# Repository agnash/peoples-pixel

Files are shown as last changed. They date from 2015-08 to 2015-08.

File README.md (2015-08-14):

Copyright (c) 2015, Aaron Nash, Dominic Schira, and James Cuadros. This file is licensed under the terms of the "GPL (v2)" license. Please see the file LICENSE.md included in this distribution for licensing terms.

Contact, issues and contributing information is at the bottom of this readme.

# The People's Pixel

This project combines a Raspberry Pi and Arduino Uno, along with necessary peripherals, to form a compact
system capable of performing user-initiated image capture and presentation, such as would be typical in a "photo-booth" machine. The system currently supports the use of a segment display as a countown timer and a button as the trigger.

This take on a DIY, portable photobooth solution is unique in that it allows builders to make use of the amateur or professional camera they may already have (compatable camera list is linked to below). Since the system separately handles all hardare accessory control via a microntroller, folks with some programming and electronics experience can extend the machine to make use of even more 'gizmos' that may enhance the user experience (i.e. a flash bulb, or print-to-tape device).

The system has been built into an initial working prototype. Our version represents only one possible enclosure design and equipment configuration. For some pictures of construction check out our [short photo blog](https://github.com/agnash/peoples-pixel/wiki/Blog). <add picture of startup splash screen to blog>

# Disclaimer
This project may involve some basic work with electronics. While the methods provided here have been tested under certain circumstances the authors of this repository are not responsible for any damage you cause to your equipment or to yourself or others. You agree to this by running any of the code or following any of the instructions included in this repository.

Please see LICENSE.md for the warrantly disclaimer.

# Platform Compatibility
The software here is only expected to run on the Raspberry-Pi (running Raspbian Wheezy) and Arduino microcontroller. Do not expect code within the raspberry-pi directory to run or even compile on other linux computers without extra configuration. The Raspberry-Pi code has been tested on the Model A+, B+, and the Version 2 Model B. The arduino code has been tested on the Arduino Uno Rev 3 and the Arduino Mega 2560 models.

# Dependencies
Credit is given to the authors of the following open source softwares on which this software currently depends. These softwares were not modified in any way, only used.

[libgphoto2](http://http://www.gphoto.org/proj/libgphoto2/) (v3, LGPL)

[Linux frame buffer application(FBI)](https://www.kraxel.org/cgit/fbida/) (v2, GPL)

(installation instructions included below)

# Parts List

Raspberry Pi (With at least 2 USB ports)

micro-USB power cable

Ethernet cable or HDMI cable (To use the pi) 

Arduino Uno Rev 3 or Arduino Mega 2560

SparkFun Logic Level Converter - Bi-Directional

Large or Massive Arcade Button with LED - 60mm or 100mm Red

7-segment common cathode LED display 

1x Full size breadboard

Large jumper cable pack (male to male)

Female to female or female to male jumper cable pack

1/4 watt resistor kit

Digital camera from the following list: http://www.gphoto.org/proj/libgphoto2/support.php

# Set up the Arduino
Follow these steps to setup the Arduino microcontroller...

1: [Download and install](https://www.arduino.cc/en/main/software) the Arduino IDE onto a compatible computer (i.e. PC/Mac/Linux but not the Raspberry-Pi).

2: Clone this repository onto that computer

``` $ git clone https://github.com/agnash/peoples-pixel.git ```

3: Connect your Arduino microcontroller to the computer's USB port and start up the Arduino IDE

4: From the top menu bar select Tools -> Boards and select the model Arduino board you are using

5: From the top menu bar select Tools -> Ports and select the USB port that the Arduino is connected to

6: Use [these instructions](https://www.arduino.cc/en/Guide/Libraries) to install the seven segment display library provided with People's Pixel. The directory to add is arduino/libraries/SegmentDisplay from within the project directory you cloned in step 2.

7: Also open the file arduino/booth_controller/booth_controller.ino in the IDE. Use the upload button to load the software onto the Arduino board.

# Set up the Raspberry Pi
After [installing](https://www.raspberrypi.org/documentation/installation/installing-images/README.md) Raspbian Wheezy ...

1: Run the command:
``` $ df -h ```
to make sure your file system is roughly size the of your sdcard (less the size of the OS. You can confirm the size of the card with $ sudo fdisk -l). If for some reason the file system is really small compared what you were expecting, run

``` $ sudo raspi-config ```
and select the option for increasing the size of the filesystem. Exit the config app.

2: Run the command:

``` $ sudo apt-get update ```

3: Run the command:

``` $ sudo raspi-config ```
and select advanced options. Then select the option for enabling i2c hardware at startup. Exit the config app.

4: Run the command:

``` $ sudo nano /etc/modprobe.d/raspi-blacklist.conf ```

'i2c-bcm2708' shouldn't be blacklisted so make sure that line is commented out. i.e.
``` #blacklist i2c-bcm2708 ```

Save the file if changed and exit nano. (If the file is empty then just move on)

5: Run the command:

``` $ sudo nano /etc/modules ``` Append the lines...
```
i2c-bcm2708 
i2c-dev 
```
if they're not already there. Save the file if changed and exit nano.

6: Reboot the raspberry-pi

7: Install git (It might already be installed - confirm with $ git --version):

``` $ sudo apt-get install git ```

8: Get libgphoto2 and development files

``` $ sudo apt-get install libgphoto2-2 libgphoto2-2-dev```

9: Get the Linux frame buffer application

```$ sudo apt-get install fbi```

10: Clone the peoples-pixel repo:

```$ cd ~ ```

```$ git clone https://github.com/agnash/peoples-pixel.git```

#Final Installation and Configuration
(the following assumes you cloned the project into your home directory as demonstrated above)

1: Run the following commands
```
$ cd ~/peoples-pixel/raspberry-pi
$ sudo ./setup.bash
```
2: ***Optional:*** If you'd like the welcome splash to appear upon startup then run the command ```$ nano ~/.bashrc``` and add the line
```export PP_HOME=/home/<your user name>/peoples-pixel```

Save and exit the file.

You can make the welcome image anything you'd like, as long as it's called welcome.png and is located in the raspberry-pi directory in the main project directory.

3: ***Optional:*** If you'd like People's Pixel to startup automatically when you boot up the Raspberry Pi then run the command ```$ sudo nano /etc/rc.local``` and add the following lines to the script:
```
export PP_HOME=/home/<your user name>/peoples-pixel
sudo -E pp
```

(The first line will enable the welcome image to be shown if you plan on using it)
Save and exit the file.

4: The program can now manually be started by running the command:

```$ sudo pp```

The program will fail unless the camera and Arduino are properly configured, powered on and connected. The wiki contains the [wiring diagram](https://github.com/agnash/peoples-pixel/wiki/Example-Wiring-Diagram).

#Updating
(the following assumes you cloned the project into your home directory)

1: Run the commands:
```
$ cd ~/peoples-pixel
$ git checkout master
$ git pull
$ cd raspberry-pi
$ sudo ./setup.bash
```

If updates include changes to code running on the Arduino, these will be pointed out in corresponding release notes. Specific instructions will be outlined there.

# Contact and Contributing
Please see the profile pages for [Aaron Nash](https://github.com/agnash) and [Dominic Schira](https://github.com/domshyra) and [James Cuadros](https://github.com/jamescuadros) for contact information.

See the issues section for current issue tracking. If you'd like to contribute first fork your own copy of the repository. After commiting the feature branch containing your changes to your own repository create a pull request targeting this one. If approved, all changes should go into the integration branch.

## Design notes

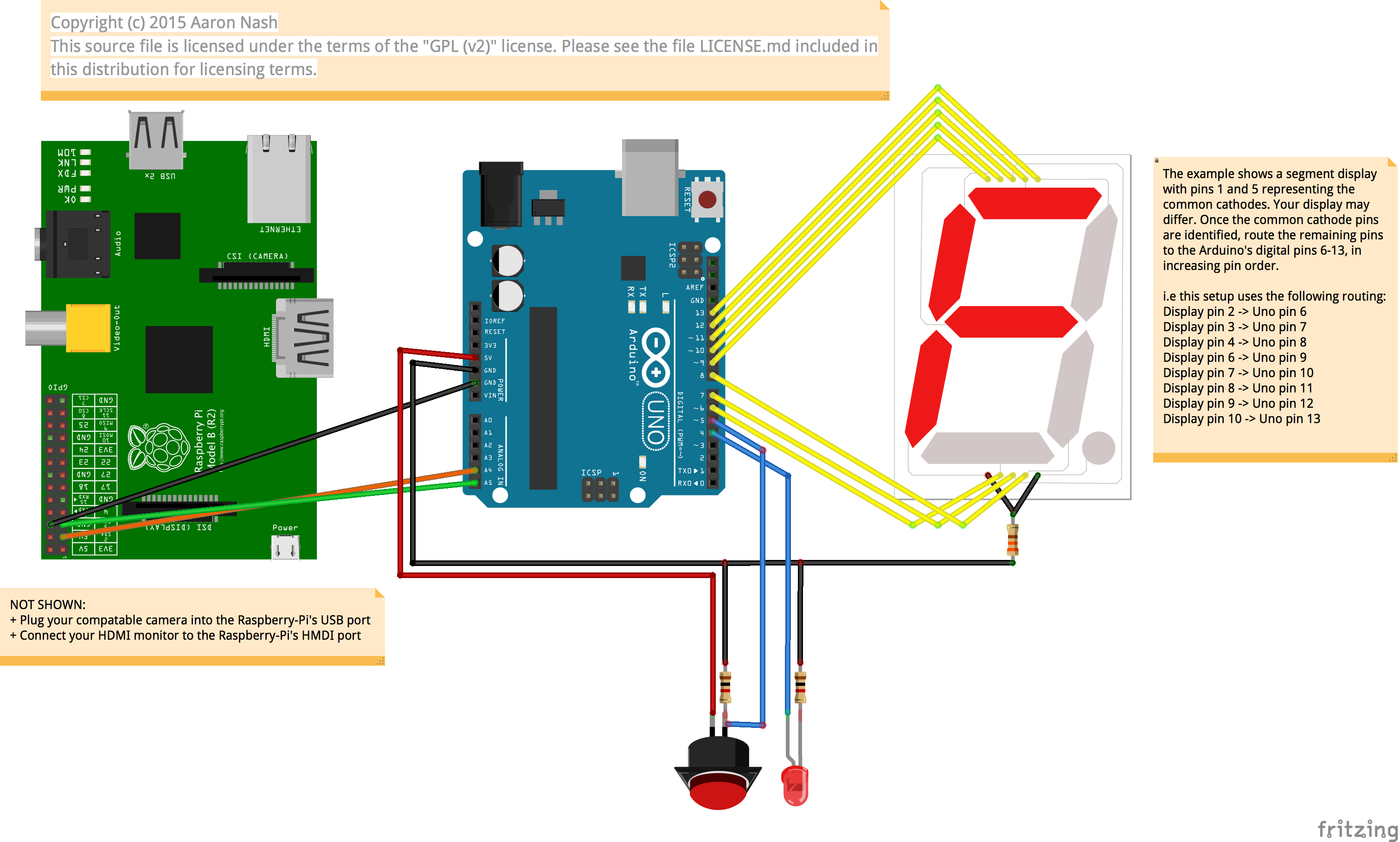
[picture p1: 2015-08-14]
resources/peoples_pixel_bb.png

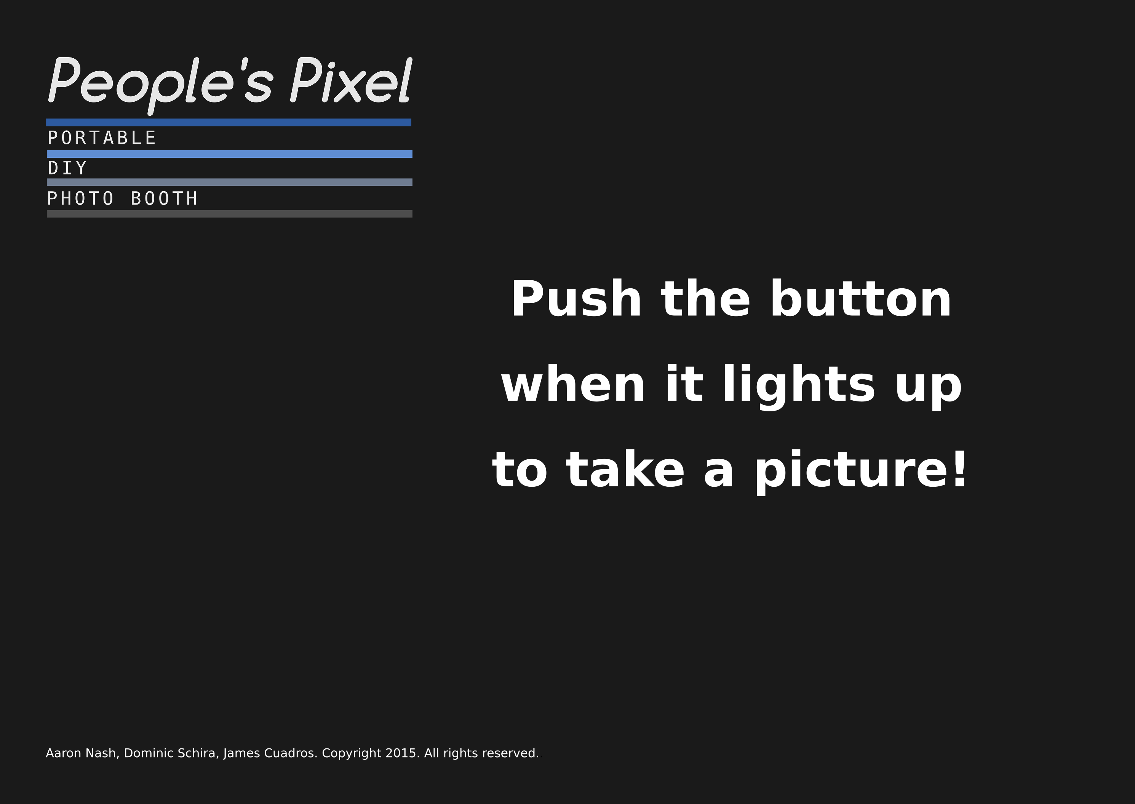
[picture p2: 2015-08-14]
raspberry-pi/welcome.png

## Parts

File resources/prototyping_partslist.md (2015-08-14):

Copyright (c) 2015, Aaron Nash. This file is licensed under the terms of the "GPL (v2)" license. Please see the file LICENSE.md included in this distribution for licensing terms.

-------------------------------------------------------------------------------------------------------------------

These are some of the parts used to build the initial prototype of the photo booth:

~$40 - Raspberry Pi (Model A+, B+, or Version 2 Model B)

~$10 - USB to ethernet adapter (Only if using R-Pi Model A+)

~$25 - Arduino Uno Rev 3 or Arduino Mega 2560

~$3 - SparkFun Logic Level Converter - Bi-Directional (https://www.sparkfun.com/products/12009)

~$5 to $10 - Large or Massive Arcade Button with LED - 60mm or 100mm Red (i.e http://www.adafruit.com/products/1190)

~$8 - 2.3" 7-segment common cathode LED display (i.e. http://www.mouser.com/ProductDetail/Kingbright/SC23-12SRWA/?qs=sGAEpiMZZMvkC18yXH9iIlPqJScb4RGnGXJSKMkoMWw%3d)

~$6 - 1x Full size breadboard (i.e. https://www.sparkfun.com/products/12615)

~$5 - Large jumper cable pack (male to male - i.e. https://www.sparkfun.com/products/11026)

~$2 - Female to female or female to male jumper cable pack (i.e. https://www.sparkfun.com/products/12796)

~$7 - 1/4 watt resistor kit (i.e. http://www.makershed.com/products/make-1-4-watt-resistor-kit-365pc)

Digital camera from the following list: http://www.gphoto.org/proj/libgphoto2/support.php

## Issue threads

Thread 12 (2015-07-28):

pp forces MCU reboot on startup

agnash, 2015-07-28:

agnash, 2015-07-30:
Not really a 100% correct way to do a complete software reboot of the Arduino. Instead, will reset all program state by executing setup().

Closed 2015-08-14.

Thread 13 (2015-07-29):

pp.c to auto-detect active i2c device on Raspberry Pi

agnash, 2015-07-29:
Right now the i2c device is hard-coded into the program, but the device number may vary between 0 and 1 depending on the model R-Pi that is being used. Best case: the program should determine this automatically. At a minimum, the device can be passed in as an argument.

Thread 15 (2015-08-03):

Restarting pp sometimes results in PTP I/O Error - Can't find camera

agnash, 2015-08-03:
Ideas:

+ Child processes preventing some camera resources from being freed?
+ Bug in libgphoto2 gp_camera_exit or gp_camera_unref routines?
+ Bug somewhere else in out of date libgphoto2?
+ USB not resetting? Out of date libusb?

work around: power cycle the camera and try again

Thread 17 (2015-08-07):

No Arduino reset if corrupted I2C connection

agnash, 2015-08-07:
The arduino can be effectively 'reset' if pp is manually started from a terminal. However, if the R-Pi is power-cycled and the arduino isn't, the i2c connection can be corrupted and then the initial arduino-reset command can fail.

Workaround: always power-cycle both devices.

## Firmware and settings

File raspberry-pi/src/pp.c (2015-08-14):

// Copyright (c) 2015 Aaron Nash
//
// This source file is licensed under the terms of the "GPL (v2)" license.
// Please see the file LICENSE.md included in this distribution for licensing
// terms.
//

#include <sys/mman.h>
#include <sys/types.h>
#include <sys/ioctl.h>
#include <signal.h>
#include <wait.h>
#include <string.h>
#include <unistd.h>
#include <errno.h>
#include <stdio.h>
#include <stdlib.h>
#include <time.h>
#include <linux/i2c-dev.h>
#include <fcntl.h>
#include <stdarg.h>
#include <unistd.h>
#include <stdbool.h>
#include <gphoto2/gphoto2-camera.h>
#include <gphoto2/gphoto2-context.h>

// specify the device name of the i2c bus
static const char *DEVICE = "/dev/i2c-1";

// path of the welcome image
static const char *WELCOME = "/raspberry-pi/welcome.png";

// the name given to whatever image was last fetched from camera
static const char *CURRENT_IMAGE = "current_image";

// specify the arduino slave address
static const int ADDRESS = 0x04;

// seconds controller waits for image viewer to finish buffering image on screen
static const int SLEEP_TIME = 5;

// the error timeout duration on arduino communication
static const time_t STANDARD_TIMEOUT = 5;

// codes that can be received from the Raspberry-Pi
enum SendCodes {RESET = 0, ARM = 1, DISARM = 2, TRIGGER = 3, FAULT = 4};

// codes that can be sent to the Raspberry-Pi
enum ReceiveCodes {NANR = 0, AR = 1, ANR = 2, CAP = 3, ERR = 4};

// libgphoto camera and context
GPContext *context;
Camera *camera;

// flag for child process
bool child = false;

// prototypes
static void ctx_error_func (GPContext *context,
	const char *format,
	va_list args,
	void *data);
static void ctx_status_func (GPContext *context,
	const char *format,
	va_list args,
	void *data);
void communicate(const int msg, const int file);
void proceedOnResponse(const int expected, const time_t timeout, const int file);
void takePicture(GPContext *context, Camera *camera, const char *filename);
void cleanFbi();
void bufferImage(const char *imagePath);
void cleanup();
void handleSIGINT(int sig);

// main
int main(int argc, char **argv) {

	int file, ret, quit;
	CameraText text;

	// register the exit function
	quit = atexit(cleanup);	
	
	// register the interrupt handler
	signal(SIGINT, handleSIGINT);

	context = gp_context_new();

	gp_context_set_error_func (context, ctx_error_func, NULL);
	gp_context_set_status_func (context, ctx_status_func, NULL);

	gp_camera_new(&camera);

	// try to find a camera, terminate if none found
	ret = gp_camera_init(camera, context);
	if (ret < GP_OK) {
		printf("No camera auto detected\n");
		gp_camera_free(camera);
		exit(-1);
	}

	// return the found camera's configuration info, terminate if error
	ret = gp_camera_get_summary(camera, &text, context);
	if (ret < GP_OK) {
		printf("Camera failed retrieving summary\n");
		gp_camera_free(camera);
		exit(-1);
	}

	// print summary of selected camera
	printf("Summary:\n%s\n", text.text);

	// try to open i2c device, terminate if no active i2c device
	if ((file = open(DEVICE, O_RDWR)) < 0) {
		printf("Failed to open i2c device");
		exit(-1);
	}

	// try to connect to bus, terminate on failed connection
	if (ioctl(file, I2C_SLAVE, ADDRESS) < 0) {
		printf("Failed to connect to slave at address %d\n", ADDRESS);
		exit(-1);
	}
	
	// before entering main loop, force a microcontroller reset
	printf("Resetting microcontroller...\n");
	communicate(RESET, file);
	proceedOnResponse(NANR, STANDARD_TIMEOUT, file);
	printf("Microcontroller reset\n");
	
	// build path of welcome image and render it
	char *ppPath = getenv("PP_HOME");
	if (ppPath == NULL) {
		printf("Skipping welcome image - pp home directory is not set\n");
	} else {
		char *welcome = malloc(strlen(ppPath) + strlen(WELCOME) + 1);
		if (welcome == NULL) {
			printf("Skipping welcome image - can't resolve path\n");
		} else {
			strcpy(welcome, ppPath);
			strcat(welcome, WELCOME);
			printf("Loading splash: %s\n", welcome);
			bufferImage(welcome);
			free(welcome);
		}
	}
	
	// delay the button for a few seconds
	sleep(SLEEP_TIME);
	
	// main controller loop
	printf("Entering main loop\n");
	while (1) {

		// arm the arduino
		printf("Arming the microcontroller...\n");
		communicate(ARM, file);
		proceedOnResponse(AR, STANDARD_TIMEOUT, file);
		printf("Microcontroller armed\n");

		// wait for countdown to finish (errors out after an hour of inactivity)
		proceedOnResponse(CAP, 3600, file);

		// take the picture
		printf("Taking picture!\n");
		takePicture(context, camera, CURRENT_IMAGE);

		// now disarm
		printf("Disarming...\n");
		communicate(DISARM, file);
		proceedOnResponse(NANR, STANDARD_TIMEOUT, file);
		printf("Microcontroller disarmed\n");

		// clean up any previous fbi processes
		cleanFbi();
		// load the new image
		bufferImage(CURRENT_IMAGE);

		// parent - give first child time to buffer image to screen
		printf("Pi sleeping for %d seconds...\n", SLEEP_TIME);
		sleep(SLEEP_TIME);

		// wake up
		printf("We're back!\n");
	}
}

void communicate(const int msg, const int file) {
	
	unsigned char command[16];
	
	command[0] = msg;
	if (write(file, command, 1) == 1) {
		// write was successful, give the arduino a second to process
		usleep(1000000);
	} else {
		printf("Failed to write code %d to microcontroller\n", msg);
		exit(-1);
	}
}

void proceedOnResponse(const int expected, const time_t timeout, const int file) {
	
	unsigned char response[1];
	
	// bytes read
	int bytes;
	// for calculating the timeout
	time_t currTime;

	// get seconds since epoch
	time_t startTime = time(NULL);
	if (startTime == (time_t) -1) {
		printf("Failed to get current time\n");
		exit(-1);
	}

	// poll for response
	while ((bytes = read(file, response, 1)) == 1) {
		currTime = time(NULL);
		if (currTime == (time_t) -1) {
			printf("Failed to get current time\n");
			exit(-1);
		} else if (currTime > startTime + timeout) {
			printf("Microcontroller communication timeout");
			communicate(ERR, file);
			exit(-1);
		}

		if ((int) response[0] == expected) {
			break;
		}
	}

	// read error handling
	if (bytes < 0) {
		printf("Error reading from microcontroller\n");
		exit(-1);
	}
}

static void ctx_error_func(GPContext *context,
	const char *format,
	va_list args,
	void *data) {
        fprintf  (stderr, "\n");
        fprintf  (stderr, "*** Contexterror ***              \n");
        vfprintf (stderr, format, args);
        fprintf  (stderr, "\n");
        fflush   (stderr);
}

static void ctx_status_func(GPContext *context,
	const char *format,
	va_list args,
	void *data) {
        vfprintf (stderr, format, args);
        fprintf  (stderr, "\n");
        fflush   (stderr);
}

void takePicture(GPContext *context, Camera *camera, const char *filename) {
	int fd, ret = 0;
	CameraFile *file;
	CameraFilePath cameraFilePath;

	ret = gp_camera_capture(camera, GP_CAPTURE_IMAGE, &cameraFilePath, context);

	if (ret < GP_OK) {
		printf("Camera failed to capture image\n");
		gp_camera_free(camera);
		exit(-1);
	}
	printf("Image captured was %s/%s\n", cameraFilePath.folder, cameraFilePath.name);
	fd = open(filename, O_CREAT | O_WRONLY, 0644);
 	ret = gp_file_new_from_fd(&file, fd);

 	if (ret < GP_OK) {
		printf("Couldn't create destination file on Raspberry Pi\n");
		exit(-1);
 	}

	ret = gp_camera_file_get(camera, cameraFilePath.folder, cameraFilePath.name,  GP_FILE_TYPE_NORMAL, file, context);

 	if (ret < GP_OK) {
		printf("Couldn't copy image from camera\n");
		exit(-1);
 	}

	gp_file_free(file);
}

void cleanFbi() {
	// fork child process
	int killStatus;
	int pid = fork();

	if (pid >= 0) {
		// fork was successful
		if (pid == 0) {
			// child
			child = true;

			// kill fbi processes by command name
			int err = execl("/usr/bin/killall", "killall", "/usr/bin/fbi", (char *) NULL);

			if (err < 0) {
				printf("Failed to terminate fbi processes: %d\n", err);
				exit(-1);
			}
		} else {
			// parent
			
			// wait for child to kill fbi processes (sends SIGTERM)
			if (pid != waitpid(pid, &killStatus, 0)) {
				printf("Error in fbi cleaning process\n");
				exit(-1);
			}
		}
	} else {
		// child failed to fork
		printf("No process to terminate image viewer\n");
		exit(-1);
	}
}

void bufferImage(const char *imagePath) {
	// fork child process
	int pid = fork();

	if (pid >= 0) {
		// fork was successful
		if (pid == 0) {
			// child
			child = true;
			
			// start fbi image viewer
			int err = execl("/usr/bin/fbi",
			"fbi",
			"-T",
			"2",
			"-d",
			"/dev/fb0",
			"-noverbose",
			"-a",
			imagePath,
			(char *) NULL);

			if (err < 0) {
				printf("Failed to start image viewer\n");
				exit(-1);
			}
		}
	} else {
		// child failed to fork
		printf("No process for image viewer\n");
		exit(-1);
	}
}

void cleanup() {
	if (!child) {
		printf("\nCleaning up residual fbi processes and releasing resources...\n");
		cleanFbi();
		gp_camera_exit(camera, context);
		gp_camera_unref(camera);
		printf("Done\n");
	}
}

void handleSIGINT(int sig) {
	
	exit(0);
}

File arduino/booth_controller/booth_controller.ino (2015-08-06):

// Copyright (c) 2015 Aaron Nash
//
// This source file is licensed under the terms of the "GPL (v2)" license.
// Please see the file LICENSE.md included in this distribution for licensing
// terms.
//

#include <Wire.h>
#include <SegmentDisplay.h>

// after bit shifting will be converted to I2C slave address 8
#define SLAVE_ADDRESS 0x04

SegmentDisplay segmentDisplay;

// ready indicator led pin and last state
const char readyPin = 4;
int lastReadyState;

// user button pin and state
const char buttonPin = 5;
int buttonState;

// countdown timer = 5 seconds
const long interval = 5000;

// codes that can be received from the Raspberry-Pi
enum Commands: byte {RESET = 0, ARM = 1, DISARM = 2, TRIGGER = 3, FAULT = 4};
Commands receives;

// codes that can be sent to the Raspberry-Pi
enum States: byte {NANR = 0, AR = 1, ANR = 2, CAP = 3, ERR = 4};
States sends;

// current state and last message
byte state;
byte msg;

void setup() {
  // start I2C slave
  Wire.begin(SLAVE_ADDRESS);

  // I2C communication callbacks
  Wire.onReceive(receiveData);
  Wire.onRequest(sendData);



  // setup the common cathode segment display
  segmentDisplay.initialize(6, 7, 8, 9, 10, 11, 12, 13);

  // set the readyPin to OUTPUT
  pinMode(readyPin, OUTPUT);

  // set the buttonPin to INPUT
  pinMode(buttonPin, INPUT);

  // set initial states
  buttonState = LOW;
  digitalWrite(readyPin, LOW);
  segmentDisplay.clear();
  state = NANR;
  msg = DISARM;
}

void loop() {

  if (msg == RESET) {
    setup();
  }

  if (state == NANR && msg == ARM) {
    state = AR;
    digitalWrite(readyPin, HIGH);
  }

  /*****************************************************************
  so that countdown triggering can happen remotely or via the button
  *****************************************************************/
  if ((buttonState = digitalRead(buttonPin)) == HIGH) {
    msg = TRIGGER;
  }
  /****************************************************************/

  if (state == AR && msg == TRIGGER) {
    state = ANR;
    digitalWrite(readyPin, LOW);
    countdown();
    state = CAP;
  }

  if (msg == DISARM) {
    state = NANR;
  }

  if (msg == FAULT) {
    state = ERR;
  }

  if (state == ERR) {
    segmentDisplay.print(ERROR);
  }
}

void receiveData(int numBytes) {
  while (Wire.available()) {
    msg = Wire.read();
  }
}

void sendData() {
  // send the outgoing code
  Wire.write(state);
}

// nonblocking countdown timer
void countdown() {
  long curr = millis();
  long delta = millis() - curr;
  while ((interval - delta) >= 0) {

    segmentDisplay.print((((interval - delta)) / 1000) + 1);

    delta = millis() - curr;
  }

  segmentDisplay.clear();
}

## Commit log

2015-06-05 Adds I2C-ready skeleton of mcu sketch
2015-06-11 Adds a temporary arming simulation button and lcd read-out
2015-06-16 adds nonblocking countdown timer algorithm in booth_controller.ino
    Not tested yet
2015-06-17 Fixes countdown timer and adds additional state
    [booth_controller.ino]
2015-06-24 Sets valid i2c slave address of Arduino
2015-06-24 Adds proper functionality for i2c receiveData callback
2015-06-24 Adds simple while loop to test i2c writes
2015-06-25 Adds basic arm-disarm loop to test i2c communication
2015-06-25 Removes a print stmt
2015-06-25 Creates new handlers for incoming i2c data
2015-06-28 Addresses some compilation errors in SegmentDisplay
    [booth_controller.ino]
2015-07-09 Adds camera scanning code to pp.cpp
2015-07-09 Adds working camera scanner to pp.c
2015-07-13 Removes temporary prototyping code from Arduino sketch
2015-07-23 Simplifies pid handling in pp.c
2015-07-28 Fixes check on fork success
    [pp.c]
2015-07-29 Refactors arduino code for simple single state
2015-08-03 Fixes execl syscalls in pp.c
    [pp.c]
2015-08-03 Adds example wiring diagram
2015-08-03 Adds fritzing file to resources
    [peoples_pixel.fzz]
2015-08-10 fixes segment display component of wiring diagram
    [peoples_pixel.fzz]
2015-08-14 Adds Arduino setup instructions
